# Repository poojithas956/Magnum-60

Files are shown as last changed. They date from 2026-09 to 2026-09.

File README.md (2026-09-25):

# Magnum60
Magnum60 is my custom 60% mechanical keyboard project built around an RP2040-ZERO controller.
<p>
I wanted a keyboard that felt clean and simple like a classic 60%, but still let me fully understand how the electronics actually work (matrix, diodes, routing, and firmware pin mapping), not just buy a kit and screw it together.
</p>

## Why I made this

I use my keyboard for school every day, so I wanted to build one that is actually mine from scratch.

Main goals I set for myself:
- Design a full 60% PCB in KiCad (61 keys)
- Use hot-swap MX footprints so it is easy to test switches
- Keep the design manufacturable and not just a concept render
- Learn the full pipeline: schematic -> PCB -> 3D model -> production files

## Project status

This repo includes the complete hardware design files and manufacturing outputs:
- KiCad project, schematic, and PCB
- 3D CAD export (.step)
- Plate DXF
- Production files (BOM, positions, designators, netlist)
- Custom RP2040-ZERO symbol/footprint library files

Current hardware summary:
- Layout: 60% ANSI style, 61 keys
- Controller: RP2040-ZERO
- Matrix: diode matrix (1 diode per switch)
- Stabilizers: 2u, 2.25u, 2.75u, 6.25u support

## Images

### Wiring / schematic screenshot

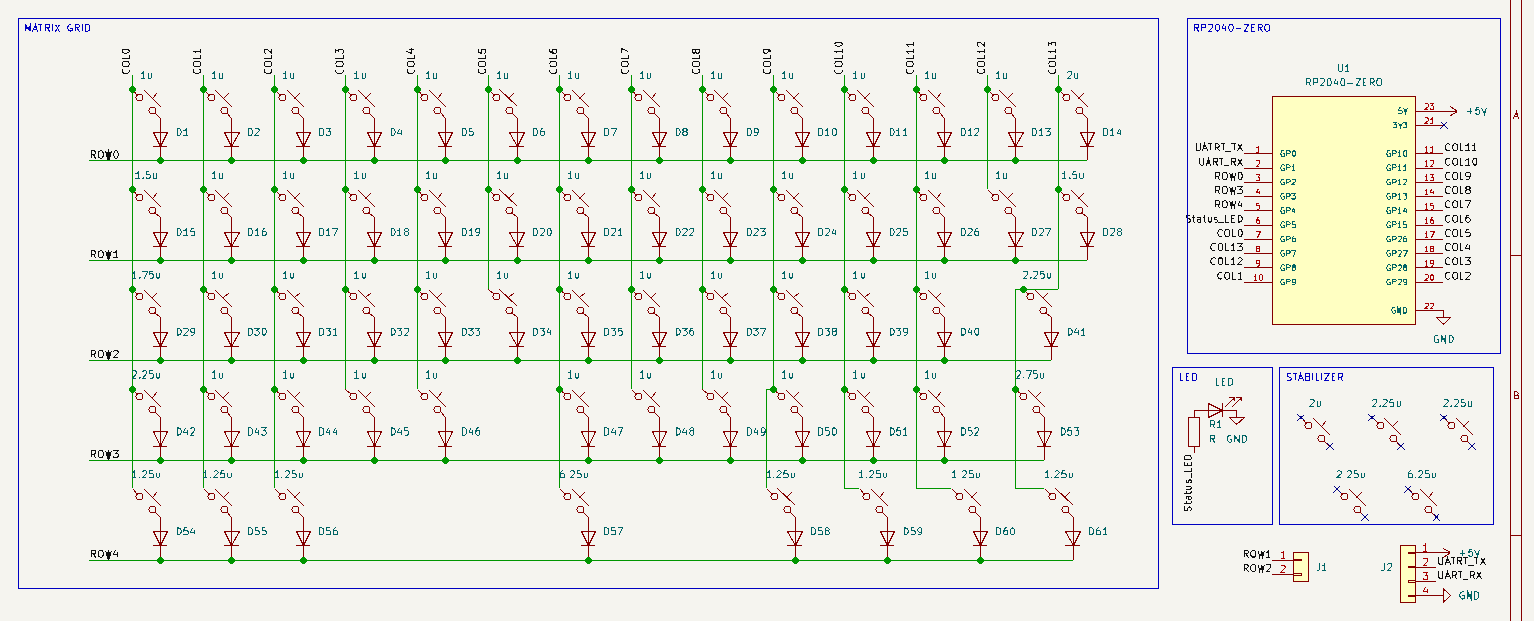
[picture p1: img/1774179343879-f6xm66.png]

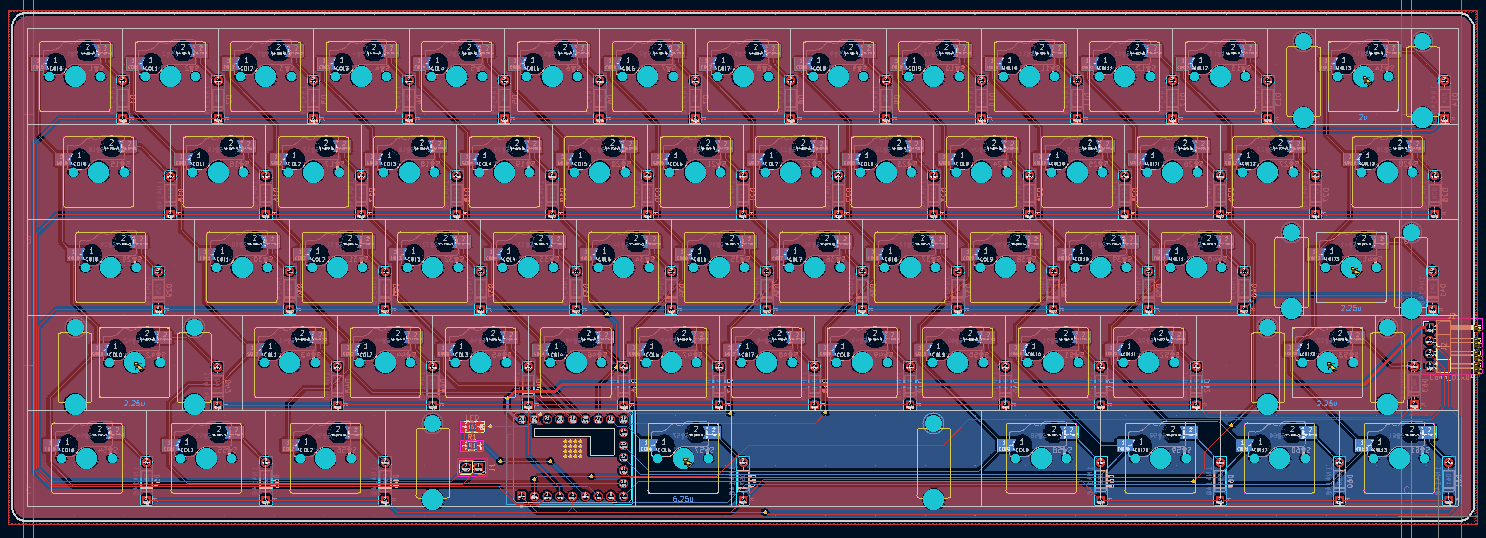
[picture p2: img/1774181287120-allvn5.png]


### Other Screenshots













## CAD

OnShape: [link](https://cad.onshape.com/documents/b52a919955139e6a718853bb/w/34cf3e6613baa59e9155a7be/e/0783ed61a417fa509f3e5ed3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)

## Firmware note

A KMK starter firmware is included in this repo:

- `firmware/kmk/main.py`
- `firmware/kmk/README.md`

It includes the row/column pin mapping from the current netlist and a base ANSI-like 61-key layout.

## BOM (summary)

Current BOM is in `bom.csv`.

| Name | Purpose | Quantity | Total Cost (USD) | Distributor | Link |
|---|---|---:|---:|---|---|
| 3D printed Case | 3D printing | 1 | 8.19 | Hack Club | https://printlegion.hackclub.com |
| PCB fabrication | PCB | 1 | 39.20 | Robu.in | https://robu.in/product/online-pcb-manufacturing-service/ |
| RP2040-zero | Microcontroller | 1 | 6.05 | Robu.in | https://robu.in/product/waveshare-rp2040-zero-raspberry-pi-mcu-with-presoldered-header/ |
| Cherry PBT Keycaps | Keycaps | 1 | 17.47 | Curiosity Caps | https://curiositycaps.in/products/counter-strike-printstream-decal-collectio-n-cherry-pbt-keycaps |
| Durock Smokey Screw-In Stabilizers V2 | Stabilizers | 1 | 17.00 | StacksKB | https://stackskb.com/store/durock-smokey-screw-in-stabilizers-v2/ |
| Akko V5 Creamy Blue Pro Switch (Pack of 45) | For typing I guess ? | 1 | 13.14 | StacksKB | https://stackskb.com/store/akko-v5-creamy-blue-pro-switch-pack-of-45/ |

**Total BOM cost:** 101.05 USD

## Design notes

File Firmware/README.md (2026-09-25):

# Aegis60 KMK Firmware

This is a starter KMK firmware for the Aegis60 (RP2040-ZERO).

## What this includes
- Exact row/column GPIO mapping from the current hardware netlist
- 61-key ANSI-like base layer
- Sparse matrix handling with `KC.NO` for physically empty matrix slots

## Flash steps
1. Install CircuitPython on RP2040-ZERO (if not already installed).
2. Copy the KMK library folder to your `CIRCUITPY` drive.
3. Copy `main.py` from this folder to the root of `CIRCUITPY`.
4. Replug/reset the board.

## Notes
- Matrix diode direction is configured as `COL2ROW`.
- In the schematic/netlist, GP0/GP1 are named `UATRT_TX` / `UART_RX` but are used as matrix rows in this design.
- If any key appears in the wrong place, verify switch orientation and matrix continuity first, then tune keycodes in `main.py`.

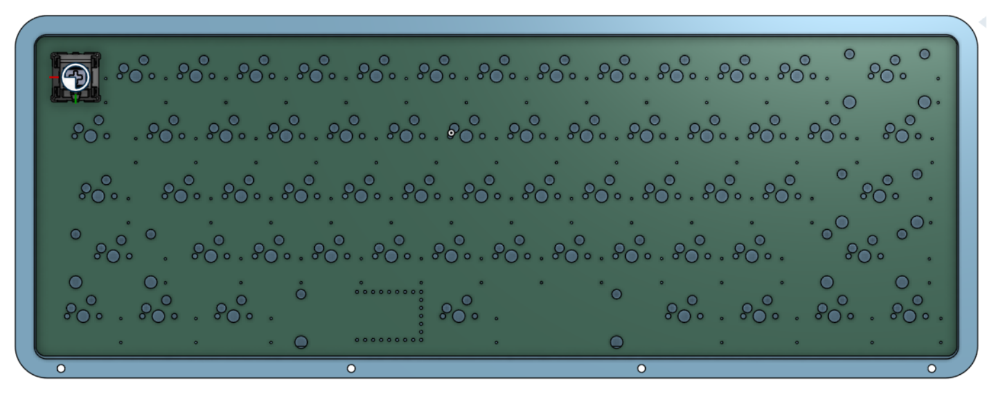
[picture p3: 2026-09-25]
img/1773319982806-2vnl15.png

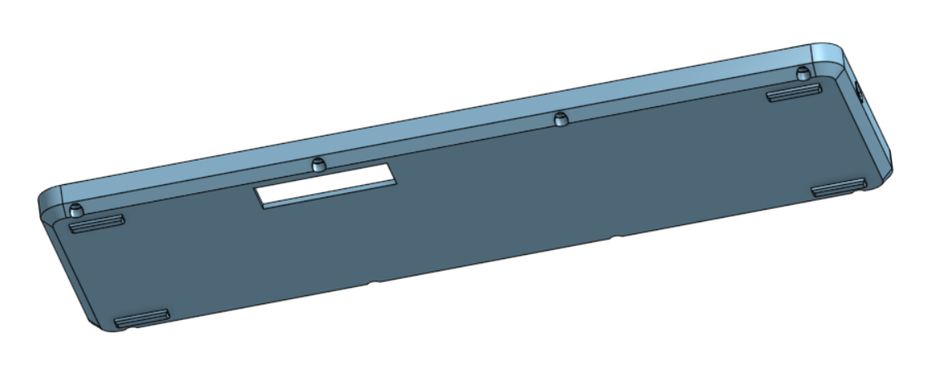
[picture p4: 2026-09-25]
img/1775487929557-t3bdbg.png

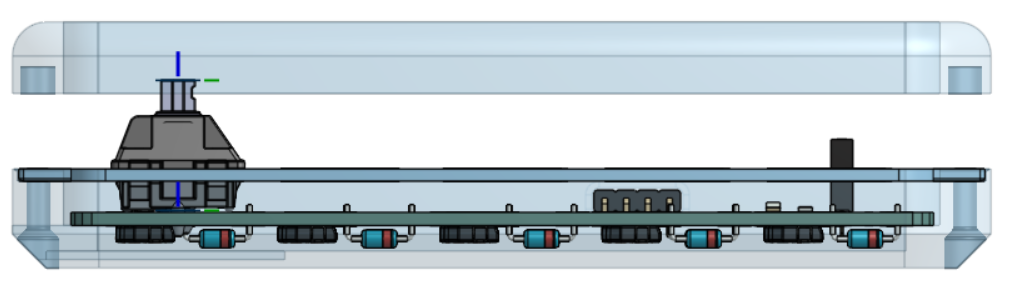
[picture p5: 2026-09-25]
img/1774182063378-dn6pcz.png

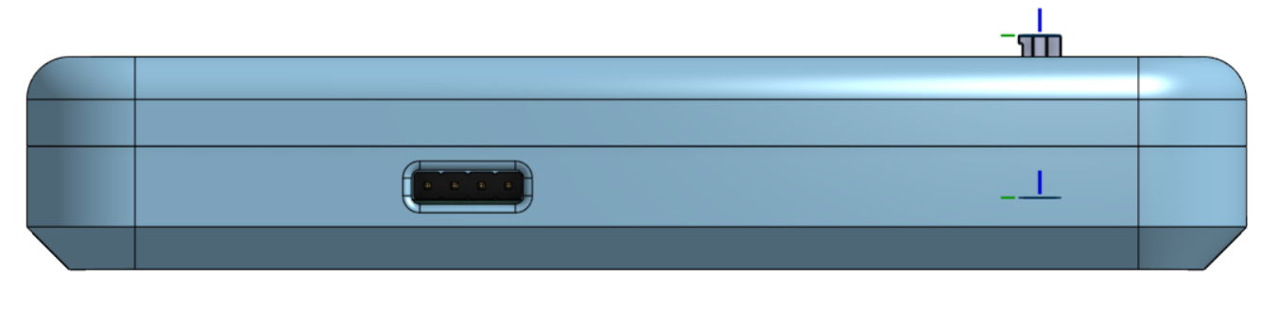
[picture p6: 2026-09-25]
img/1774182108578-rt90xz.png

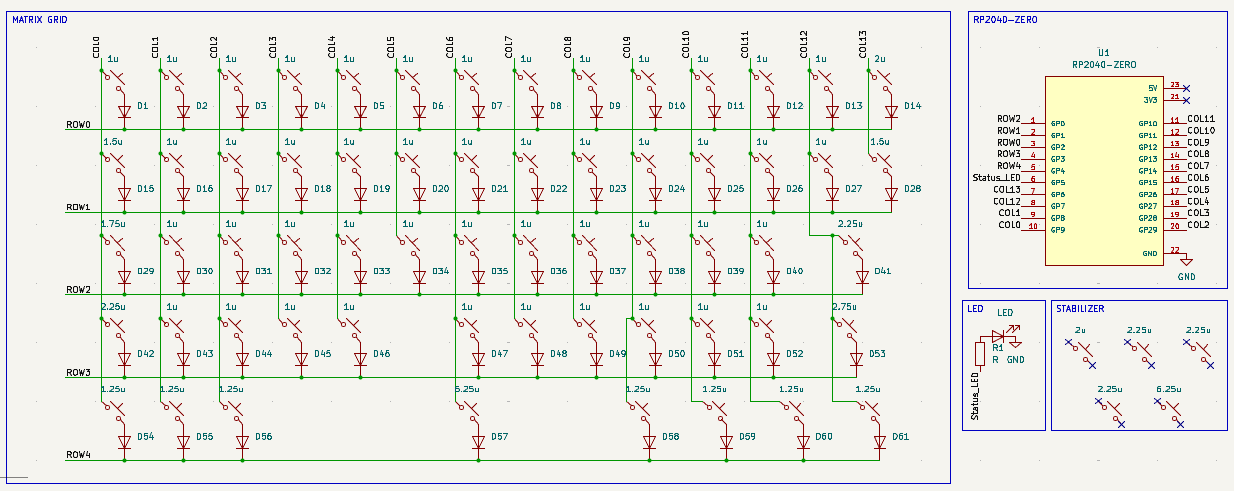
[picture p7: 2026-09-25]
img/1773064059539-6njlxo.png

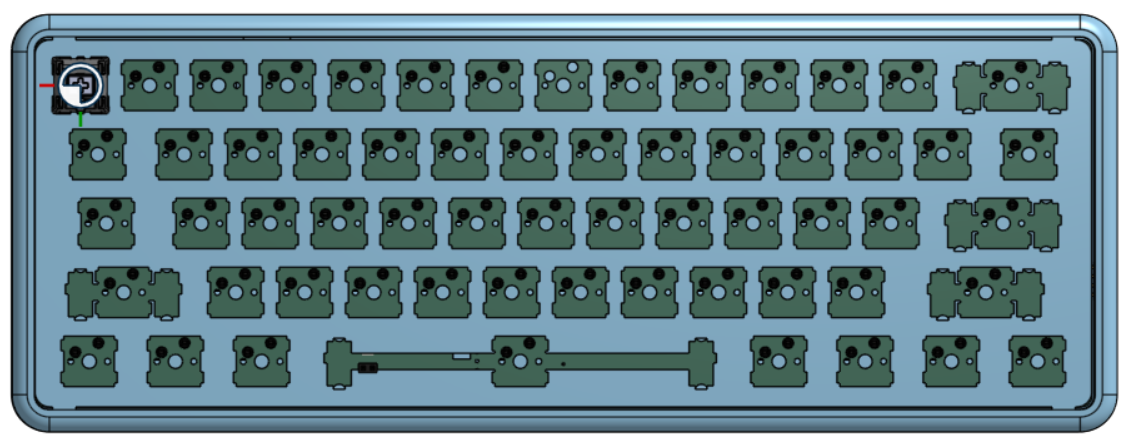
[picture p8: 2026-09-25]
img/1774182351158-30hg6s.png

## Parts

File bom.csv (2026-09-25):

Name | Purpose | Quantity | Total Cost (USD) | Link | Distributor
3D printed Case | 3D printing | 1 | 8.19 | https://printlegion.hackclub.com | Hack Club
PCB fabrication | PCB | 1 | 39.20 | https://robu.in/product/online-pcb-manufacturing-service/ | Robu.in
RP2040-zero | Microcontroller | 1 | 6.05 | https://robu.in/product/waveshare-rp2040-zero-raspberry-pi-mcu-with-presoldered-header/ | Robu.in
Cherry PBT Keycaps | Keycaps | 1 | 17.47 | https://curiositycaps.in/products/counter-strike-printstream-decal-collectio-n-cherry-pbt-keycaps | Curiosity Caps
Durock Smokey Screw-In Stabilizers V2 | Stabilizers | 1 | 17.00 | https://stackskb.com/store/durock-smokey-screw-in-stabilizers-v2/ | StacksKB
Akko V5 Creamy Blue Pro Switch (Pack of 45) | For typing I guess ? | 1 | 13.14 | https://stackskb.com/store/akko-v5-creamy-blue-pro-switch-pack-of-45/ | StacksKB

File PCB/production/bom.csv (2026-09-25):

Designator | Footprint | Quantity | Value | LCSC Part #
D1, D10, D11, D12, D13, D14, D15, D16, D17, D18, D19, D2, D20, D21, D22, D23, D24, D25, D26, D27, D28, D29, D3, D30, D31, D32, D33, D34, D35, D36, D37, D38, D39, D4, D40, D41, D42, D43, D44, D45, D46, D47, D48, D49, D5, D50, D51, D52, D53, D54, D55, D56, D57, D58, D59, D6, D60, D61, D7, D8, D9 | D_DO-35_SOD27_P7.62mm_Horizontal | 61 | 1N4148
D62 | 1206 | 1 | LED
J1 | PinSocket_1x02_P2.54mm_Vertical | 1 | Conn_01x02
J2 | PinHeader_1x04_P2.54mm_Horizontal | 1 | Conn_01x04
R1 | 1206 | 1 | R
STAB1 | STAB_MX_2u | 1 | 2u
STAB2, STAB3 | STAB_MX_2.25u | 2 | 2.25u
STAB4 | STAB_MX_2.75u | 1 | 2.25u
STAB5 | STAB_MX_6.25u | 1 | 6.25u
SW1, SW10, SW11, SW12, SW13, SW16, SW17, SW18, SW19, SW2, SW20, SW21, SW22, SW23, SW24, SW25, SW26, SW27, SW3, SW30, SW31, SW32, SW33, SW34, SW35, SW36, SW37, SW38, SW39, SW4, SW40, SW43, SW44, SW45, SW46, SW47, SW48, SW49, SW5, SW50, SW51, SW52, SW6, SW7, SW8, SW9 | SW_MX_HS_KS-2P02B01-01_1u | 46 | 1u
SW14 | SW_MX_HS_KS-2P02B01-01_1u | 1 | 2u
SW15, SW28 | SW_MX_HS_KS-2P02B01-01_1.5u | 2 | 1.5u
SW29 | SW_MX_HS_KS-2P02B01-01_1.75u | 1 | 1.75u
SW41, SW42 | SW_MX_HS_KS-2P02B01-01_1u | 2 | 2.25u
SW53 | SW_MX_HS_KS-2P02B01-01_1u | 1 | 2.75u
SW54, SW55, SW56, SW58, SW59, SW60, SW61 | SW_MX_HS_KS-2P02B01-01_1.25u | 7 | 1.25u
SW57 | SW_MX_HS_KS-2P02B01-01_1u | 1 | 6.25u
U1 | MODULE_RP2040-ZERO | 1 | RP2040-ZERO

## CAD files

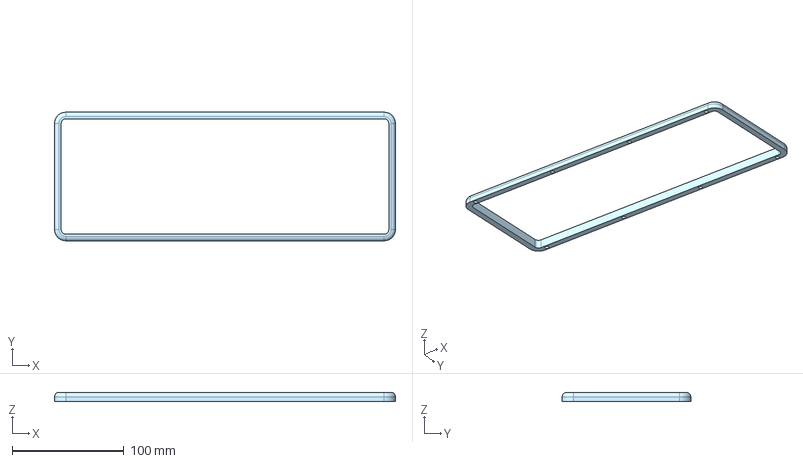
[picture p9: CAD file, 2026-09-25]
CAD/Cover.step
305.0 x 115.0 x 8.40 mm

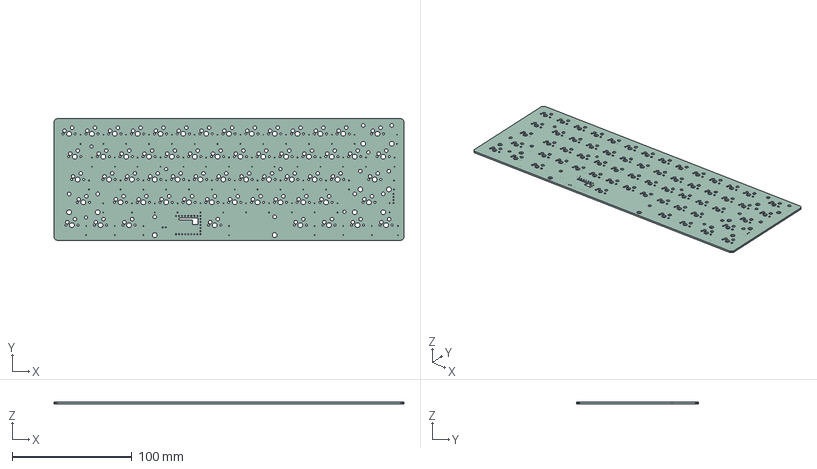
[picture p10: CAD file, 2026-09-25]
PCB/Magnum60.step
291.8 x 101.3 x 1.51 mm

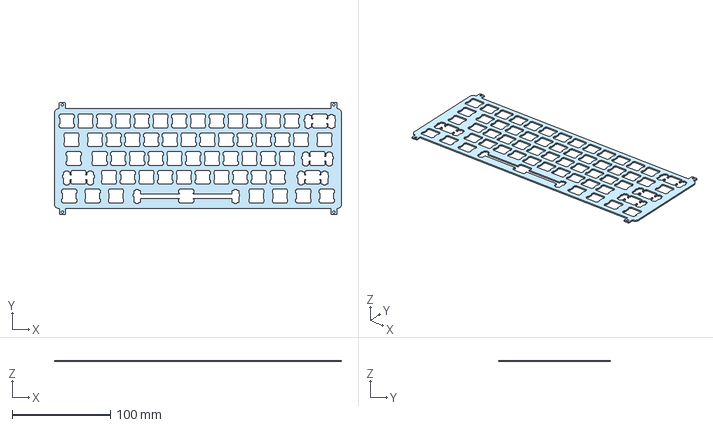
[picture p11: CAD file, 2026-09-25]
CAD/Plate.step
291.7 x 113.4 x 1.40 mm

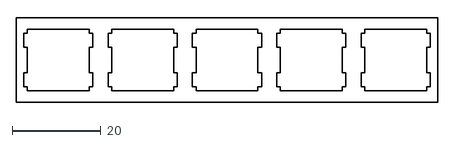
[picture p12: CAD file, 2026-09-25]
PCB/Plate.dxf
95.3 x 19.1

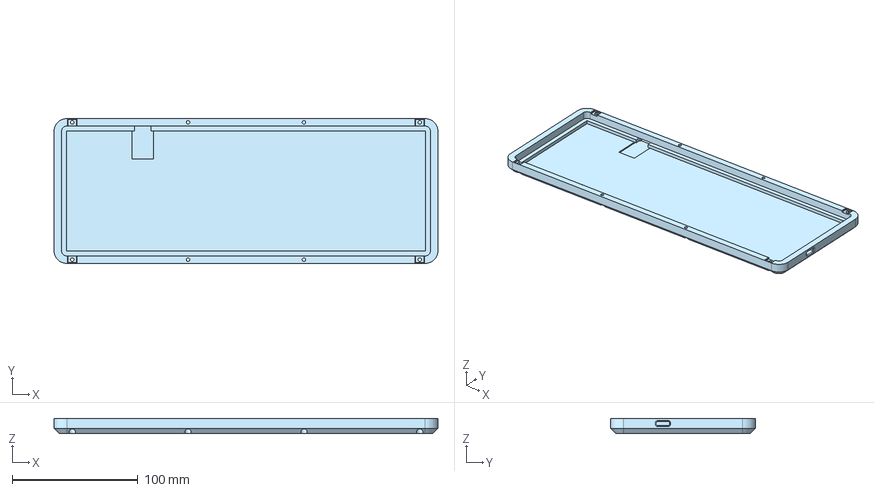
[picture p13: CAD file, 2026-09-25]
CAD/Bottom_Case.step
305.0 x 115.0 x 11.6 mm

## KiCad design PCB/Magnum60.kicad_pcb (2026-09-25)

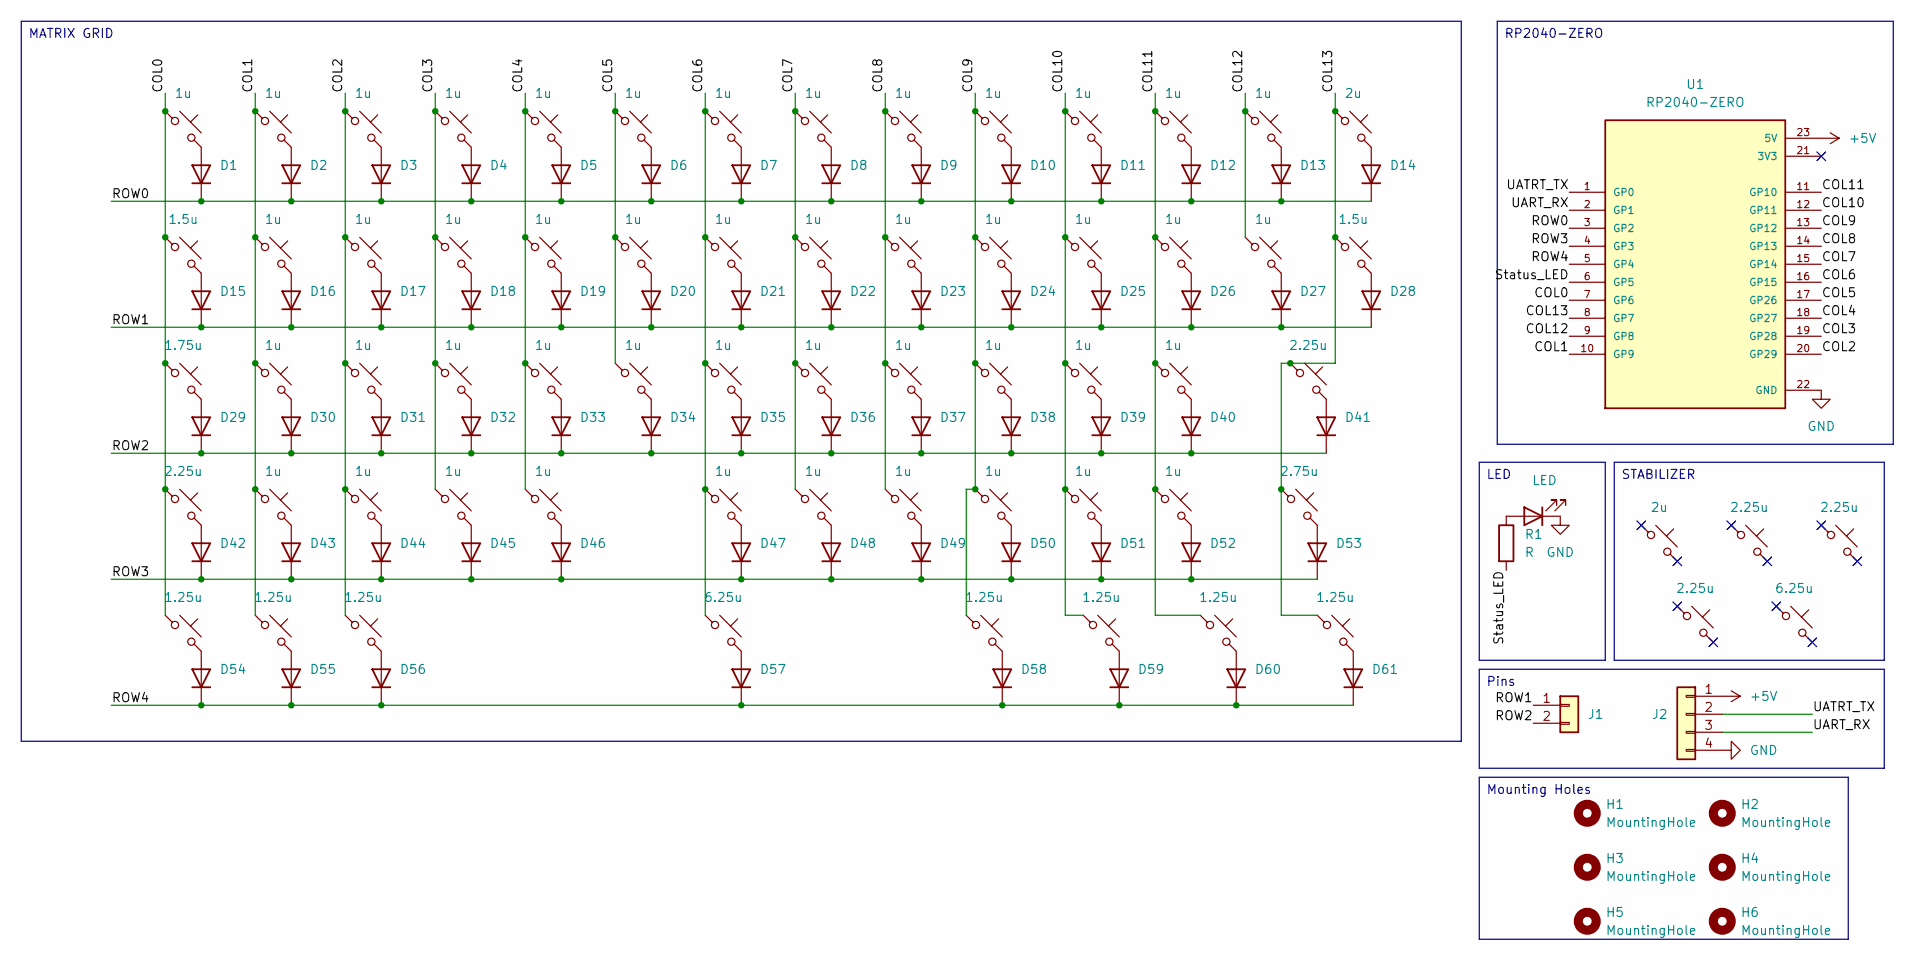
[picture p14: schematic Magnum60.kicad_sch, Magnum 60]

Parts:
D1, D2, D3, D4, D5, D6, D7, D8, D9, D10, D11, D12, D13, D14, D15, D16, D17, D18, D19, D20, D21, D22, D23, D24, D25, D26, D27, D28, D29, D30, D31, D32, D33, D34, D35, D36, D37, D38, D39, D40, D41, D42, D43, D44, D45, D46, D47, D48, D49, D50, D51, D52, D53, D54, D55, D56, D57, D58, D59, D60, D61: 1N4148; D_DO-35_SOD27_P7.62mm_Horizontal
D62: LED; LED_1206_3216Metric_Pad1.42x1.75mm_HandSolder
H1, H2, H3, H4, H5, H6: MountingHole; MountingHole_2.7mm_M2.5
J1: Conn_01x02; PinSocket_1x02_P2.54mm_Vertical
J2: Conn_01x04; PinHeader_1x04_P2.54mm_Horizontal
R1: R; R_1206_3216Metric
STAB1: 2u; STAB_MX_2u
STAB2, STAB3: 2.25u; STAB_MX_2.25u
STAB4: 2.25u; STAB_MX_2.75u
STAB5: 6.25u; STAB_MX_6.25u
SW1, SW2, SW3, SW4, SW5, SW6, SW7, SW8, SW9, SW10, SW11, SW12, SW13, SW16, SW17, SW18, SW19, SW20, SW21, SW22, SW23, SW24, SW25, SW26, SW27, SW30, SW31, SW32, SW33, SW34, SW35, SW36, SW37, SW38, SW39, SW40, SW43, SW44, SW45, SW46, SW47, SW48, SW49, SW50, SW51, SW52: 1u; SW_MX_HS_KS-2P02B01-01_1u
SW14: 2u; SW_MX_HS_KS-2P02B01-01_1u
SW15, SW28: 1.5u; SW_MX_HS_KS-2P02B01-01_1.5u
SW29: 1.75u; SW_MX_HS_KS-2P02B01-01_1.75u
SW41, SW42: 2.25u; SW_MX_HS_KS-2P02B01-01_1u
SW53: 2.75u; SW_MX_HS_KS-2P02B01-01_1u
SW54, SW55, SW56, SW58, SW59, SW60, SW61: 1.25u; SW_MX_HS_KS-2P02B01-01_1.25u
SW57: 6.25u; SW_MX_HS_KS-2P02B01-01_1u
U1: RP2040-ZERO; MODULE_RP2040-ZERO; PARTREV NA

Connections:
+5V: J2.1, U1.23 (5V)
/COL0: SW1.1, SW15.1, SW29.1, SW42.1, SW54.1, U1.7 (GP6)
/COL1: SW2.1, SW16.1, SW30.1, SW43.1, SW55.1, U1.10 (GP9)
/COL2: SW3.1, SW17.1, SW31.1, SW44.1, SW56.1, U1.20 (GP29)
/COL3: SW4.1, SW18.1, SW32.1, SW45.1, U1.19 (GP28)
/COL4: SW5.1, SW19.1, SW33.1, SW46.1, U1.18 (GP27)
/COL5: SW6.1, SW20.1, SW34.1, U1.17 (GP26)
/COL6: SW7.1, SW21.1, SW35.1, SW47.1, SW57.1, U1.16 (GP15)
/COL7: SW8.1, SW22.1, SW36.1, SW48.1, U1.15 (GP14)
/COL8: SW9.1, SW23.1, SW37.1, SW49.1, U1.14 (GP13)
/COL9: SW10.1, SW24.1, SW38.1, SW50.1, SW58.1, U1.13 (GP12)
/COL10: SW11.1, SW25.1, SW39.1, SW51.1, SW59.1, U1.12 (GP11)
/COL11: SW12.1, SW26.1, SW40.1, SW52.1, SW60.1, U1.11 (GP10)
/COL12: SW13.1, SW27.1, U1.9 (GP8)
/COL13: SW14.1, SW28.1, SW41.1, SW53.1, SW61.1, U1.8 (GP7)
/ROW0: D1.1 (K), D2.1 (K), D3.1 (K), D4.1 (K), D5.1 (K), D6.1 (K), D7.1 (K), D8.1 (K), D9.1 (K), D10.1 (K), D11.1 (K), D12.1 (K), D13.1 (K), D14.1 (K), U1.3 (GP2)
/ROW1: D15.1 (K), D16.1 (K), D17.1 (K), D18.1 (K), D19.1 (K), D20.1 (K), D21.1 (K), D22.1 (K), D23.1 (K), D24.1 (K), D25.1 (K), D26.1 (K), D27.1 (K), D28.1 (K), J1.1
/ROW2: D29.1 (K), D30.1 (K), D31.1 (K), D32.1 (K), D33.1 (K), D34.1 (K), D35.1 (K), D36.1 (K), D37.1 (K), D38.1 (K), D39.1 (K), D40.1 (K), D41.1 (K), J1.2
/ROW3: D42.1 (K), D43.1 (K), D44.1 (K), D45.1 (K), D46.1 (K), D47.1 (K), D48.1 (K), D49.1 (K), D50.1 (K), D51.1 (K), D52.1 (K), D53.1 (K), U1.4 (GP3)
/ROW4: D54.1 (K), D55.1 (K), D56.1 (K), D57.1 (K), D58.1 (K), D59.1 (K), D60.1 (K), D61.1 (K), U1.5 (GP4)
/Status_LED: R1.2, U1.6 (GP5)
/UART_RX: J2.3, U1.2 (GP1)
/UATRT_TX: J2.2, U1.1 (GP0)
GND: D62.1 (K), J2.4, U1.22 (GND)
unnamed: D1.2 (A), SW1.2
unnamed: D2.2 (A), SW2.2
unnamed: D3.2 (A), SW3.2
unnamed: D4.2 (A), SW4.2
unnamed: D5.2 (A), SW5.2
unnamed: D6.2 (A), SW6.2
unnamed: D7.2 (A), SW7.2
unnamed: D8.2 (A), SW8.2
unnamed: D9.2 (A), SW9.2
unnamed: D10.2 (A), SW10.2
unnamed: D11.2 (A), SW11.2
unnamed: D12.2 (A), SW12.2
unnamed: D13.2 (A), SW13.2
unnamed: D14.2 (A), SW14.2
unnamed: D15.2 (A), SW15.2
unnamed: D16.2 (A), SW16.2
unnamed: D17.2 (A), SW17.2
unnamed: D18.2 (A), SW18.2
unnamed: D19.2 (A), SW19.2
unnamed: D20.2 (A), SW20.2
unnamed: D21.2 (A), SW21.2
unnamed: D22.2 (A), SW22.2
unnamed: D23.2 (A), SW23.2
unnamed: D24.2 (A), SW24.2
unnamed: D25.2 (A), SW25.2
unnamed: D26.2 (A), SW26.2
unnamed: D27.2 (A), SW27.2
unnamed: D28.2 (A), SW28.2
unnamed: D29.2 (A), SW29.2
unnamed: D30.2 (A), SW30.2
unnamed: D31.2 (A), SW31.2
unnamed: D32.2 (A), SW32.2
unnamed: D33.2 (A), SW33.2
unnamed: D34.2 (A), SW34.2
unnamed: D35.2 (A), SW35.2
unnamed: D36.2 (A), SW36.2
unnamed: D37.2 (A), SW37.2
unnamed: D38.2 (A), SW38.2
unnamed: D39.2 (A), SW39.2
unnamed: D40.2 (A), SW40.2
unnamed: D41.2 (A), SW41.2
unnamed: D42.2 (A), SW42.2
unnamed: D43.2 (A), SW43.2
unnamed: D44.2 (A), SW44.2
unnamed: D45.2 (A), SW45.2
unnamed: D46.2 (A), SW46.2
unnamed: D47.2 (A), SW47.2
unnamed: D48.2 (A), SW48.2
unnamed: D49.2 (A), SW49.2
unnamed: D50.2 (A), SW50.2
unnamed: D51.2 (A), SW51.2
unnamed: D52.2 (A), SW52.2
unnamed: D53.2 (A), SW53.2
unnamed: D54.2 (A), SW54.2
unnamed: D55.2 (A), SW55.2
unnamed: D56.2 (A), SW56.2
unnamed: D57.2 (A), SW57.2
unnamed: D58.2 (A), SW58.2
unnamed: D59.2 (A), SW59.2
unnamed: D60.2 (A), SW60.2
unnamed: D61.2 (A), SW61.2
unnamed: D62.2 (A), R1.1

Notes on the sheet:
STABILIZER
RP2040-ZERO
LED
MATRIX GRID
Mounting Holes
Pins

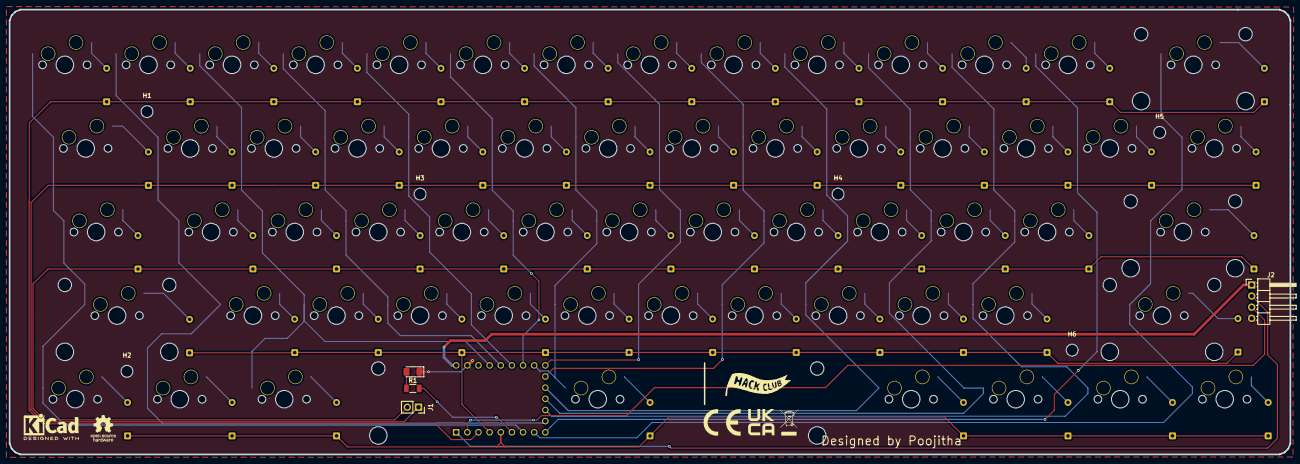
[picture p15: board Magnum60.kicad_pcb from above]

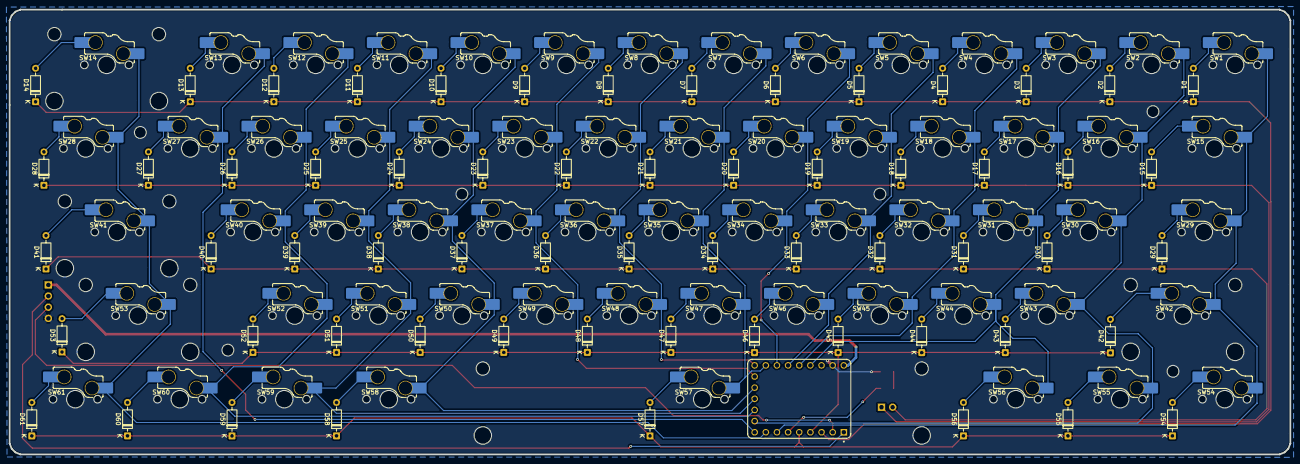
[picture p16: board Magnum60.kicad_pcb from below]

Board: 2 copper layers, 291.8 x 101.3 mm, 138 parts (123 on the bottom side), 86 nets.

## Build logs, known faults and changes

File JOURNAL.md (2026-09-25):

---
title: "Magnum60"
author: "poojithas536"
description: "A compact 60% mechanical keyboard designed for minimal desk space."
created_at: "2026-09-25"
---

# 2026-09-25: BOM

**Total time spent: 1 hr 10min**

| Name | Purpose | Quantity | Total Cost (USD) | Distributor | Link |
|---|---|---:|---:|---|---|
| 3D printed Case | 3D printing | 1 | x | Hack Club | https://printlegion.hackclub.com |
| PCB fabrication | PCB | 1 | 39.20 | Robu.in | https://robu.in/product/online-pcb-manufacturing-service/ |
| RP2040-zero | Microcontroller | 1 | 6.05 | Robu.in | https://robu.in/product/waveshare-rp2040-zero-raspberry-pi-mcu-with-presoldered-header/ |
| Cherry PBT Keycaps | Keycaps | 1 | 17.47 | Curiosity Caps | https://curiositycaps.in/products/counter-strike-printstream-decal-collectio-n-cherry-pbt-keycaps |
| Durock Smokey Screw-In Stabilizers V2 | Stabilizers | 1 | 17.00 | StacksKB | https://stackskb.com/store/durock-smokey-screw-in-stabilizers-v2/ |
| Akko V5 Creamy Blue Pro Switch (Pack of 45) | For typing I guess ? | 1 | 13.14 | StacksKB | https://stackskb.com/store/akko-v5-creamy-blue-pro-switch-pack-of-45/ |

**Total BOM cost:** 92.86 USD








* If the grant is short of the required amount, I will paying it out of my own pocket.

# 2026-09-25: September 24, 2026: Keyboard Case Optimization

**Total time spent: 3 hr**

After a thorough examination, including checking the error and accuracy of my measurements, I realized that the case was too tight for the components. Because of this, I had to add a deep cutout for the MCU so it could fit properly and have some space for airflow.

However, this cutout affected the overall look and aesthetics of the case. As a last resort, I decided to add rubber pads for support—although in reality, they’re just made of PLA : / 




# 2026-09-25: September 22, 2026: Improvising the Case

**Total time spent: 4 hr**

Yea this was loooooonnnnnnnnnggggggg and ttuffff!!!!

## Phase I
 As I recently modified the pcb with the added 4pin UART extension and some routing changes and the type c breakout board, I made a revisied version of the   Case. Once done I added final touch ups like Fillet and Chamber giving it a finished look.

## Phase II
 This was probably the most stupidist and most time pass part of my project,  Drawing the Keyboard Plate . Since I wanted this to be more of a Product based and not some random prototype, I spent hours trying to perfect the plate. And ended up deleting that and using default plate generator and modifying it. 
*Could have saved an hours work : /

I modified the plate by adjusting its lenght and width according to the case and added a Fillet. Also added screw holes for securing it tightly to the case!

## Phase III
Gave it a final touch up and bit of basic rendering !

## Result








# 2026-09-25: September 20, 2026: Improvising the PCB

**Total time spent: 2hr 19min**

 So I spent the next 10-15ins on researching about the communications between two RP2040-zero's via UART, and if it could be used has an extension port ?

### Why ?
 Well cuz, I decided on building a small cute wired/wireless macropad which could be directly connected to this keyboard, so that i don't need a bunch of cables or a dongle to connect various accessories &lt;3: 

### MODs

- Do to the recent modifications, that's a 4pin (5v, D+, D-, GND) (UART), I can now connect another keeb or macropad or anything else via this UART extension without the need of an extra port or dongle.

- I also added a extrude for the USB C breakout board with slightly leaning towards the left of the keyboard. 

- Also due to constraint of avaliable GPIO pins, i resorted to using the GPIO 0 &amp; 1 for UART and shifted the ROW 1 &amp; 2 to the unsoldered GPIO pin which can be accessed on the back of the PCB.

### Result




# 2026-09-25: September 18, 2026: CADDING: Bottom Case

**Total time spent: 3hr 47min**

## Designing the Case

Designing the case was probably the **most challenging and brainstorming-heavy** part of building this keyboard. It wasn’t my first time working on something like this, but it still took a lot of thinking.
***
I spent about **half an hour researching DIY custom keyboard cases** to understand how different designs work. One thing I quickly noticed was how **expensive many custom keyboard cases are**, which made me even more motivated to design my own.

Eventually, I settled on the style I wanted: **minimalistic, clean, and professional**. I added a few **fillets and curved edges** to make the case look softer and more aesthetic instead of just a plain rectangular box.

I started by designing the **bottom case** first. One important thing I considered was clearance for the electronics. I left around **2 mm of space under the PCB** to accommodate the **through-hole solder joints** from the switches, along with a thin layer of **foam** between the PCB and the case for cushioning and sound dampening.







Software:  Onshape
***
Happy Cadding !!!

# 2026-09-25: September 15, 2026: PCB Designing

**Total time spent: 4 hr**

After finishing the schematic, I moved on to designing the PCB in **KiCad**. This part was a bit more challenging because I wanted the keyboard to stay compact while still looking *clean* and *ergonomic*.

The first step was placing all the *Cherry MX switch* footprints in the proper **60% layout**. Once the switches were aligned, I started thinking about the overall board shape. Instead of keeping the edges completely straight, I experimented with slightly curved outlines to give the PCB a more cute and soft aesthetic rather than a rigid rectangular look.

One of the trickier parts was figuring out where to place the MCU. Since I’m using the *RP2040-Zero*, its small size actually helped a lot. After trying a few different placements, I realized it could fit nicely in the empty space to the left of the 6.25u spacebar. That spot had just enough room for the board while keeping the layout clean and avoiding interference with switches and stabilizers.

Keeping everything compact without making the routing messy took some trial and error. I had to carefully arrange the diodes and traces so the matrix stayed organized while still fitting within the board’s shape.

Once the main components were placed, I began routing the traces for the matrix and connecting everything back to the MCU. After routing, I ran a few DRC checks in KiCad again to make sure there were no clearance or connectivity issues.





# 2026-09-25: September 12, 2026: Sketched the Schematic

**Total time spent: 2 hr**

After doing some research and installing the footprints for the Cherry MX switches and the RP2040-Zero, I started working on the schematic for the 60% mechanical keyboard.

It took me about an hour to sketch out the full schematic. I connected all the switches in a matrix and added the required diodes for proper key scanning. After the main circuit was done, I organized everything to make the schematic easier to read by grouping components into sections like the Matrix grid, MCU, stabilized keys, and the status LEDs.

Once everything looked good, I reviewed the schematic to check for mistakes. I also ran a few DRC (Design Rule Checks) in KiCad and fixed the small issues that popped up. After that, the schematic was clean and ready for the PCB layout stage.




# 2026-09-25: September 7, 2026: Planning the layout

**Total time spent: 45 min**

I spent around 25 minutes thinking about the keyboard layout because I wanted it to be **lightweight**, **portable**, and **efficient** in terms of usability.

For the next 20 minutes, I looked at different keyboards available in the market to find a design that had a *clean outer look*, *compact form factor*, and *good overall layout*.

After finalizing the layout and the outer case design, I drew a rough sketch of the keyboard matrix.

Based on the number of GPIO pins required, I started looking at different MCUs — from Arduinos to Raspberry Pi boards to Waveshare modules — and eventually decided to go with the ***RP2040-Zero***.

***




60% Mechanical Keyboard ANSI layout

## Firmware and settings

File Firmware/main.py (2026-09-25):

import board
from kmk.kmk_keyboard import KMKKeyboard
from kmk.keys import KC
from kmk.scanners import DiodeOrientation

keyboard = KMKKeyboard()

# RP2040-ZERO pin map from Aegis60 schematic/netlist.
keyboard.col_pins = (
    board.GP6,   # COL0
    board.GP9,   # COL1
    board.GP29,  # COL2
    board.GP28,  # COL3
    board.GP27,  # COL4
    board.GP26,  # COL5
    board.GP15,  # COL6
    board.GP14,  # COL7
    board.GP13,  # COL8
    board.GP12,  # COL9
    board.GP11,  # COL10
    board.GP10,  # COL11
    board.GP8,   # COL12
    board.GP7,   # COL13
)

keyboard.row_pins = (
    board.GP2,  # ROW0
    board.GP0,  # ROW1 (net label UATRT_TX in project files)
    board.GP1,  # ROW2 (net label UART_RX in project files)
    board.GP3,  # ROW3
    board.GP4,  # ROW4
)

keyboard.diode_orientation = DiodeOrientation.COL2ROW

NO = KC.NO

keyboard.keymap = [
    [
        KC.GRV, KC.N1, KC.N2, KC.N3, KC.N4, KC.N5, KC.N6,
        KC.N7, KC.N8, KC.N9, KC.N0, KC.MINS, KC.EQL, KC.BSPC,
    ],
    [
        KC.TAB, KC.Q, KC.W, KC.E, KC.R, KC.T, KC.Y,
        KC.U, KC.I, KC.O, KC.P, KC.LBRC, KC.RBRC, KC.BSLS,
    ],
    [
        KC.CAPS, KC.A, KC.S, KC.D, KC.F, KC.G, KC.H,
        KC.J, KC.K, KC.L, KC.SCLN, KC.QUOT, NO, KC.ENT,
    ],
    [
        KC.LSFT, KC.Z, KC.X, KC.C, KC.V, NO, KC.B,
        KC.N, KC.M, KC.COMM, KC.DOT, KC.SLSH, NO, KC.RSFT,
    ],
    [
        KC.LCTL, KC.LGUI, KC.LALT, NO, NO, NO, KC.SPC,
        NO, NO, KC.RALT, KC.RGUI, KC.APP, NO, KC.RCTL,
    ],
]

if __name__ == '__main__':
    keyboard.go()
